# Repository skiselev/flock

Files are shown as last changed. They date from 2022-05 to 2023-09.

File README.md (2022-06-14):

# Flock
Floppy Disk Controller and Real Time Clock for RC2014 compatible systems

## Table of Content
* [Overview](#overview)
  * [Specifications](#specifications)
* [Assembly Instructions](#assembly-instructions)
* [Hardware Documentation](#hardware-documentation)
  * [Schematic and PCB Layout](#schematic-and-pcb-layout)
  * [Input/Output Ports](#inputoutput-ports)
  * [Connectors](#connectors)
  * [Bill of Materials](#bill-of-materials)
* [Release Notes](#release-notes)
  * [Changes](#changes)
  * [Known Issues](#known-issues)
* [Red Tape](#red-tape)
  * [Licensing](#licensing)
  * [Trademarks](#trademarks)

## Overview
Flock is an RC2014*-compatible floppy disk controller (FDC) and real time clock (RTC) module. It designed to work with RomWBW firmware, supporting CP/M, ZSDOS, and various applications under these OSes.

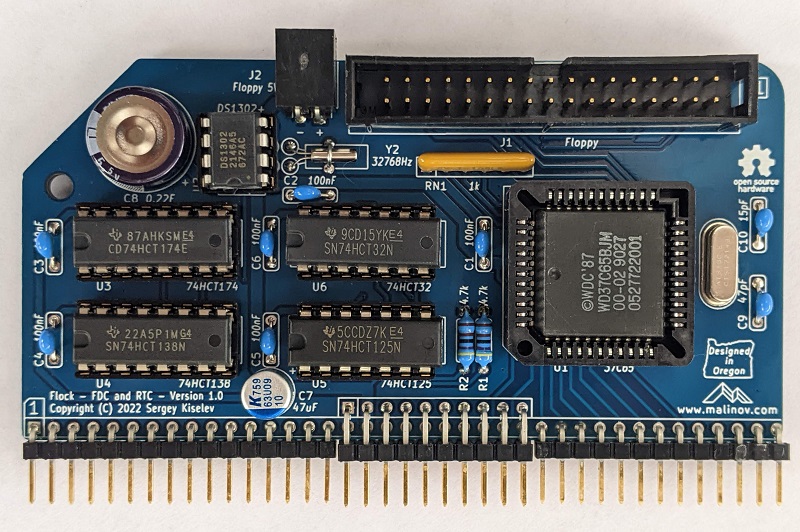
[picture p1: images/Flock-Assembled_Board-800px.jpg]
Flock Assembled Board


### Specifications
* Floppy Disk Controller: Western Digital* WD37C65 or compatible
  * NEC uPD765 compatible with an integrated data separator and floppy interface drivers and buffers
* Supported floppy disk formats:
  * 3.5", 720 KB
  * 3.5", 1.44 MB
  * 5.25", 360 KB (in 5.25", 360 KB drives only)
  * 5.25", 1.2 MB
* Supports two floppy drives, using IBM PC-like cable with twisted Disk Select / Motor Enable wires between two drives
* Real Time Clock: Maxim Integrated DS1302
* Bus: RC2014* compatible

## Assembly Instructions

Please refer to [Assembly Instructions](Assembly_Instructions.md) document

## Hardware Documentation

### Schematic and PCB Layout

[Schematic - Version 1.0](KiCad/Z80-FDC-Schematic-1.0.pdf)

[PCB Layout - Version 1.0](KiCad/Z80-FDC-Board-1.0.pdf)

### Input/Output Ports

Flock uses the following I/O ports:

#### 0x48 - FDC CCR/DIR

Write: Floppy disk controller control configuration register (CCR)
Read: Floppy disk controller digital input register (DIR)

#### 0x50 - FDC MSR

Read: Floppy disk controller master status register (MSR)

#### 0x51 - FDC Data Register

Read/Write: Data from/to floppy disk controller

#### 0x58 - FDC DOR / TC

Write: Floppy disk controller digital output register (DOR)
Read: Toggle floppy disk controller transfer complete (TC) line

#### 0xC0 - RTC

Read/Write: Access real time clock (RTC)

### Connectors

#### J1 - Floppy
Connect to floppy drive interface connector.

Pin   | Signal Name | Description | Pin   | Signal Name | Description
----- | ----------- | ------------| ----- | ----------- | -----------
J1-1  | GND         | Ground      | J1-2  | /DENSEL     | Density Select: 1 = Low density; 0 = High density
J1-3  | GND         | Ground      | J1-4  | N/C         | Not connected
J1-5  | GND         | Ground      | J1-6  | N/C         | Not connected
J1-7  | GND         | Ground      | J1-8  | /INDEX      | Index hole: 0 = At the index hole
J1-9  | GND         | Ground      | J1-10 | /MEA        | Motor Enable - Drive A
J1-11 | GND         | Ground      | J1-12 | /DSB        | Drive Select - Drive B
J1-13 | GND         | Ground      | J1-14 | /DSA        | Drive Select - Drive A
J1-15 | GND         | Ground      | J1-16 | /MEB        | Motor Enable - Drive B
J1-17 | GND         | Ground      | J1-18 | /DIR        | Direction Select
J1-19 | GND         | Ground      | J1-20 | /STEP       | Head Step
J1-21 | GND         | Ground      | J1-22 | /WDATA      | Write Data
J1-23 | GND         | Ground      | J1-24 | /WE         | Write Enable: 0 = Write Enabled
J1-25 | GND         | Ground      | J1-26 | /TRK0       | Track 00: 0 = At the track 0
J1-27 | GND         | Ground      | J1-28 | /WP         | Write Protect: 0 = Floppy disk is write protected
J1-29 | GND         | Ground      | J1-30 | /RDATA      | Read Data 
J1-31 | GND         | Ground      | J1-32 | /HDSEL      | Head Select / Side Select: 1 = Side 0; 0 = Side 1
J1-33 | GND         | Ground      | J1-34 | /DC         | Disk changed: 1 = Disk changed; 0 = Ready

#### J2 - Floppy 5V
Connect to floppy 5V power supply connector.

**Important: J2 is an unfused 5V power supply for a single 3.5" floppy disk drive. Avoid overloading and short-circuiting**

Pin | Signal Name | Description
--- | ----------- | -----------
1   | 5V          | Positive terminal - +5V
2   | GND         | Negative terminal - ground

#### J3, J4 - RC2014* Bus
Pin   | Signal Name | Description         | Pin  | Signal Name | Description
----- | ----------- | --------------------------------------- | ----- | ----------- | -----------
J3-1  | A15         | Address A15; Output                     |       |             |
J3-2  | A14         | Address A14; Output                     |       |             |
J3-3  | A13         | Address A13; Output                     |       |             |
J3-4  | A12         | Address A12; Output                     |       |             |
J3-5  | A11         | Address A11; Output                     |       |             |
J3-6  | A10         | Address A10; Output                     |       |             |
J3-7  | A9          | Address A9; Output                      |       |             |
J3-8  | A8          | Address A8; Output                      |       |             |
J3-9  | A7          | Address A7; Output                      |       |             |
J3-10 | A6          | Address A6; Output                      |       |             |
J3-11 | A5          | Address A5; Output                      |       |             |
J3-12 | A4          | Address A4; Output                      |       |             |
J3-13 | A3          | Address A3; Output                      |       |             |
J3-14 | A2          | Address A2; Output                      |       |             |
J3-15 | A1          | Address A1; Output                      |       |             |
J3-16 | A0          | Address A0; Output                      |       |             |
J3-17 | GND         | Ground                                  | J4-1  | GND         | Ground
J3-18 | VCC         | Power Supply - +5V                      | J4-2  | VCC         | Power Supply - +5V
J3-19 | /M1         | Machine Cycle One; Output               | J4-3  | /RFSH       | DRAM refresh; Output
J3-20 | /RESET      | Reset; Output                           | J4-4  | N/C         | Not connected
J3-21 | CLK1        | CPU Clock; Output                       | J4-5  | CLK2        | UART Clock (programmable); Output
J3-22 | /INT        | Interrupt; Input                        | J4-6  | /BUSACK     | DMA Bus Acknowledge; Output
J3-23 | /MREQ       | Memory Request; Output                  | J4-7  | /HALT       | Halt; Output
J3-24 | /WR         | Write Request; Output                   | J4-8  | /BUSREQ     | DMA Bus Request; Input
J3-25 | /RD         | Read Request; Output                    | J4-9  | /WAIT       | Wait; Input
J3-26 | /IORQ       | Input/Output Request; Output            | J4-10 | /NMI        | Non-maskable Interrupt; Input
J3-27 | D0          | Data D0; Input/Output                   |       |             |
J3-28 | D1          | Data D1; Input/Output                   |       |             |
J3-29 | D2          | Data D2; Input/Output                   |       |             |
J3-30 | D3          | Data D3; Input/Output                   |       |             |
J3-31 | D4          | Data D4; Input/Output                   |       |             |
J3-32 | D5          | Data D5; Input/Output                   |       |             |
J3-33 | D6          | Data D6; Input/Output                   |       |             |
J3-34 | D7          | Data D7; Input/Output                   |       |             |
J3-35 | TXDA        | Channel A, Transmit Data; Not Connected |       |             | 
J3-36 | RXDA        | Channel A, Receive Data; Not Connected  |       |             | 
J3-37 | USR1        | User Pin 1; Not connected               |       |             |
J3-38 | USR2        | User Pin 2; Not connected               |       |             |
J3-39 | USR3        | User Pin 3; Not connected               |       |             |

### Bill of Materials

#### Version 1.0

[Flock project on Mouser.com](https://www.mouser.com/ProjectManager/ProjectDetail.aspx?AccessID=5b60f70b94) - View and order all components except of the FDC and the PCB.

[Flock project on OSH Park](https://oshpark.com/shared_projects/BpUjKD43) - View and order the PCB.

Flock project on Tindie: [Complete kit](https://www.tindie.com/products/weird/flock-rc2014-compatible-module-kit/); [Flock PCB and FDC](https://www.tindie.com/products/weird/flock-rc2014-compatible-module-pcb-and-fdc/).

Component type     | Reference | Description                                 | Quantity | Possible sources and notes 
------------------ | --------- | ------------------------------------------- | -------- | --------------------------
PCB                |           | Flock PCB - Version 1.0                     | 1        | Buy from my Tindie store: [Complete kit](https://www.tindie.com/products/weird/flock-rc2014-compatible-module-kit/); [Flock PCB and FDC](https://www.tindie.com/products/weird/flock-rc2014-compatible-module-pcb-and-fdc/), or order from a PCB manufacturer of your choice using provided Gerber or KiCad files
Integrated Circuit | U1        | WD37C65BJM - FDC, CMOS, 44 pin PLCC         | 1        | eBay. Alternative: ST AIC37C65CL
Integrated Circuit | U2        | DS1302+ - RTC, 8 pin DIP                    | 1        | Mouser [700-DS1302](https://www.mouser.com/ProductDetail/700-DS1302)
Integrated Circuit | U3        | 74HCT174 - Hex D-type flip-flop with reset, 16 pin DIP | 1 | Mouser [595-CD74HCT174E](https://www.mouser.com/ProductDetail/595-CD74HCT174E)
Integrated Circuit | U4        | 74HCT138 - 3-Line to 8-Line decoders/demultiplexers, 16 pin DIP| 1 | Mouser [595-SN74HCT138NE4](https://www.mouser.com/ProductDetail/595-SN74HCT138NE4)
Integrated Circuit | U5        | 74HCT125 - Quadruple bus buffer gates with 3-state outputs, 14 pin DIP | 1 | Mouser [595-SN74HCT125NE4](https://www.mouser.com/ProductDetail/595-SN74HCT125NE4)
Integrated Circuit | U6        | 74HCT32 - Quadruple 2-input positive-OR gates, 14 pin DIP | 1 | Mouser [595-SN74HCT32NE4](https://www.mouser.com/ProductDetail/595-SN74HCT32NE4)
Quartz Crystal     | Y1        | 16 MHz, series                              | 1        | Mouser [774-ATS160-E](https://www.mouser.com/ProductDetail/774-ATS160-E)
Quartz Crystal     | Y2        | 32768 Hz, 6 pF                              | 1        | Mouser [815-AB26T32768KHZ6B](https://www.mouser.com/ProductDetail/815-AB26T32768KHZ6B)
Connector          | J1        | 2x17 pin header, shrouded, 2.54 mm pitch    | 1        | Mouser [517-30334-6002](https://www.mouser.com/ProductDetail/517-30334-6002); Alternative: Mouser [855-M20-9741746](https://www.mouser.com/ProductDetail/855-M20-9741746) (not shrouded, right angle)
Connector          | J2        | 2 pin header with friction lock, right angle | 1       | Mouser [571-2-644488-2](https://www.mouser.com/ProductDetail/571-2-644488-2)
Pin Header         | J3, J4    | 2x40 pin header, 2.54 mm pitch, right angle | 1        | Mouser [517-5121TG](https://www.mouser.com/ProductDetail/517-5121TG), or two [649-77315-118-16LF](https://www.mouser.com/ProductDetail/649-77315-118-16LF) and one [649-77317-104-20LF](https://www.mouser.com/ProductDetail/649-77317-104-20LF)
Capacitor          | C1 - C6   | 0.1 uF, 50V, MLCC, 5 mm pitch               | 6        | Mouser [810-FG28X7R1H104KNT6](https://www.mouser.com/ProductDetail/810-FG28X7R1H104KNT6)
Capacitor          | C7        | 10 uF, 63V, Organic Polymer, 6.3 mm diameter, 2.5 mm pitch | 1 | Mouser [80-A759EA106M1JAAE60](https://www.mouser.com/ProductDetail/80-A759EA106M1JAAE60)
Capacitor          | C8        | 0.22 F, 5.5V, Supercapacitor, 13.5 mm diameter, 5 mm pitch | 1 | Mouser [555-DBN-5R5D334T](https://www.mouser.com/ProductDetail/555-DBN-5R5D334T)
Capacitor          | C9        | 47 pF, 50V, MLCC, 5 mm pitch                | 6        | Mouser [810-FG28C0G2A470JNT0](https://www.mouser.com/ProductDetail/810-FG28C0G2A470JNT0)
Capacitor          | C10       | 15 pF, 50V, MLCC, 5 mm pitch                | 6        | Mouser [810-FG28C0G2A150JNT0](https://www.mouser.com/ProductDetail/810-FG28C0G2A150JNT0)
Resistor Array     | RN1       | 1 kohm, bussed, 6 pin SIP                   | 1        | Mouser [652-4606X-1LF-1K](https://www.mouser.com/ProductDetail/652-4606X-1LF-1K)
Resistor           | R1,  R2   | 4.7 kohm, 0.25 W, 1% tolerance, axial       | 2        | Mouser [603-MFR-25FRF52-4K7](https://www.mouser.com/ProductDetail/603-MFR-25FRF52-4K7)
IC Socket          | U1        | 44 pin PLCC, through hole                   | 1        | Mouser [517-8444-11B1-RK-TP](https://www.mouser.com/ProductDetail/517-8444-11B1-RK-TP)
IC Socket          | U2        | 8 pin DIP                                   | 1        | Mouser [649-DILB8P223TLF](https://www.mouser.com/ProductDetail/649-DILB8P223TLF)
IC Socket          | U3, U4    | 16 pin DIP                                  | 1        | Mouser [649-DILB16P-223TLF](https://www.mouser.com/ProductDetail/649-DILB16P-223TLF)
IC Socket          | U5, U6    | 14 pin DIP                                  | 1        | Mouser [649-DILB14P-223TLF](https://www.mouser.com/ProductDetail/649-DILB14P-223TLF)
Connector          | J2        | 2 pin connector                             | 1        | Mouser [571-3-643813-2](https://www.mouser.com/ProductDetail/571-3-643813-2)
Connector          | J2        | Floppy disk power connector housing         | 1        | Mouser [571-1718224](https://www.mouser.com/ProductDetail/571-1718224)
Connector          | J2        | Floppy disk power connector contacts        | 2        | Mouser [571-170262-2-LP](https://www.mouser.com/ProductDetail/571-170262-2-LP), [571-1702622-CT](https://www.mouser.com/ProductDetail/571-1702622-CT) (strip of 100 contacts)

## Release Notes

### Changes

* Version 1.0
  * Initial version

### Known Issues

* Version 1.0
  * No known issues

### Wishlist
* None so far

## Red Tape

### Licensing

Flock is an open source hardware project certified by [Open Source Hardware Association](https://www.oshwa.org/), certification UID is [US002115](https://certification.oshwa.org/us002115.html). The hardware design itself, including schematic and PCB layout design files are licensed under the strongly-reciprocal variant of [CERN Open Hardware Licence version 2](license-cern_ohl_s_v2.txt). The CPLD VHDL code is licensed under [GNU General Public License v3](license-gpl-3.0.txt). Documentation, including this file, is licensed under the [Creative Commons Attribution-ShareAlike 4.0 International License](license-cc-by-sa-4.0.txt).

CERN-OHL-2.0-S, GPL-3.0, CC-BY-SA-4.0

### Trademarks

* "RC2014" is a registered trademark of RFC2795 Ltd.
* Other names and brands may be claimed as the property of others.

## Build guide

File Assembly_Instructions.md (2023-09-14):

# Flock - Assembly Instructions

## Prerequisites

### Tools, Equipment, and Supplies

* Soldering iron with a fine tip. Temperature controlled soldering station is recommended
* Needle nose pliers for forming components' leads
* Small side cutters for cutting components' leads
* Multimeter with frequency measurement, an oscilloscope, or a logic analyzer can be beneficial for troubleshooting
* Desk lamp, magnifying glass
* Solder suitable for soldering electronics. For example: rosin core Sn63/Pb37, Sn60/Pb40, or a lead-free solder such as Sn96.5/Ag3.0/Cu0.5 (sometimes referred to as SAC305)
* Solder wick for removing excess of solder
* 99% Isopropyl Alcohol for removing the excess of flux after soldering
* Lint free wipes, used toothbrush, cotton swabs for cleaning the PCB before and after soldering

### Parts

The table below shows the images of the components included in the kit. The up to date list of parts provided in the [Bill of Materials](README.md#bill-of-materials) section of the [README.md](README.md) file. It also provides the recommended sources for the parts.

Image                                                                                           | Reference | Description                                            | Quantity
----------------------------------------------------------------------------------------------- | --------- | ------------------------------------------------------ | --------
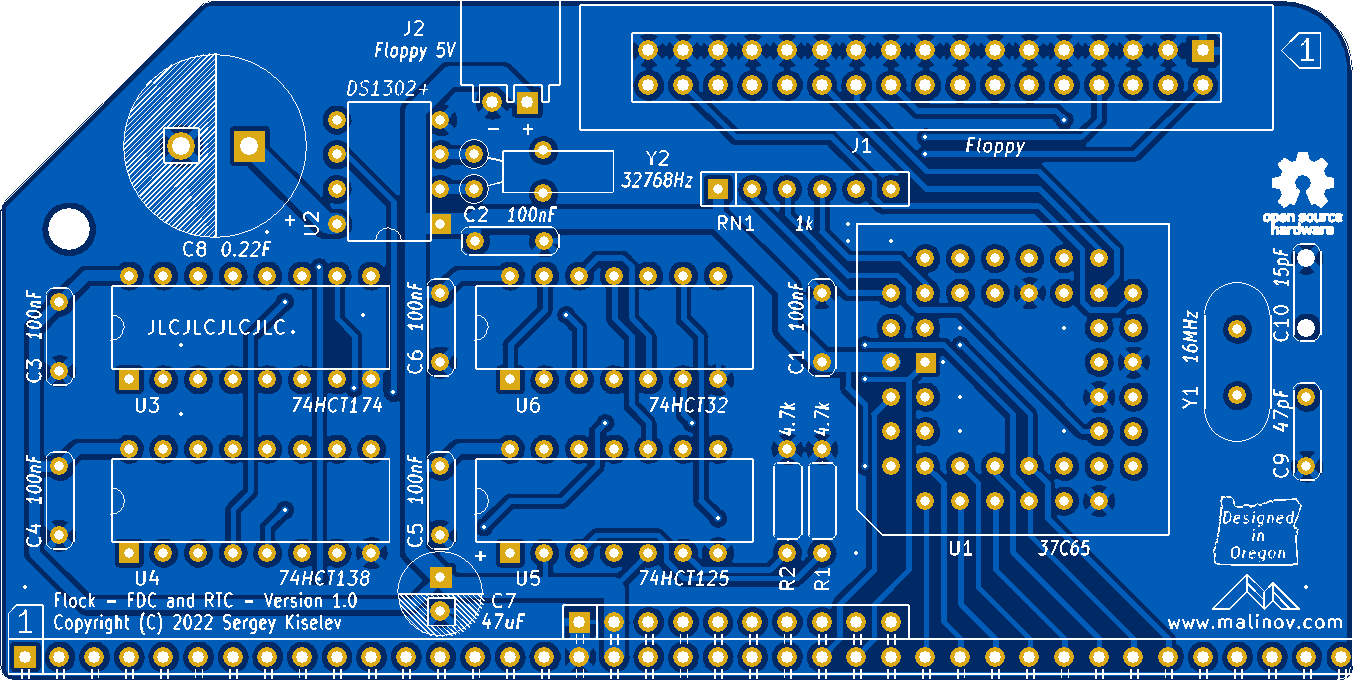
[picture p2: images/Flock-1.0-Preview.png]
PCB - Z80-512K v1.2
                 | PCB       | Flock PCB - Version 1.0                                | 1
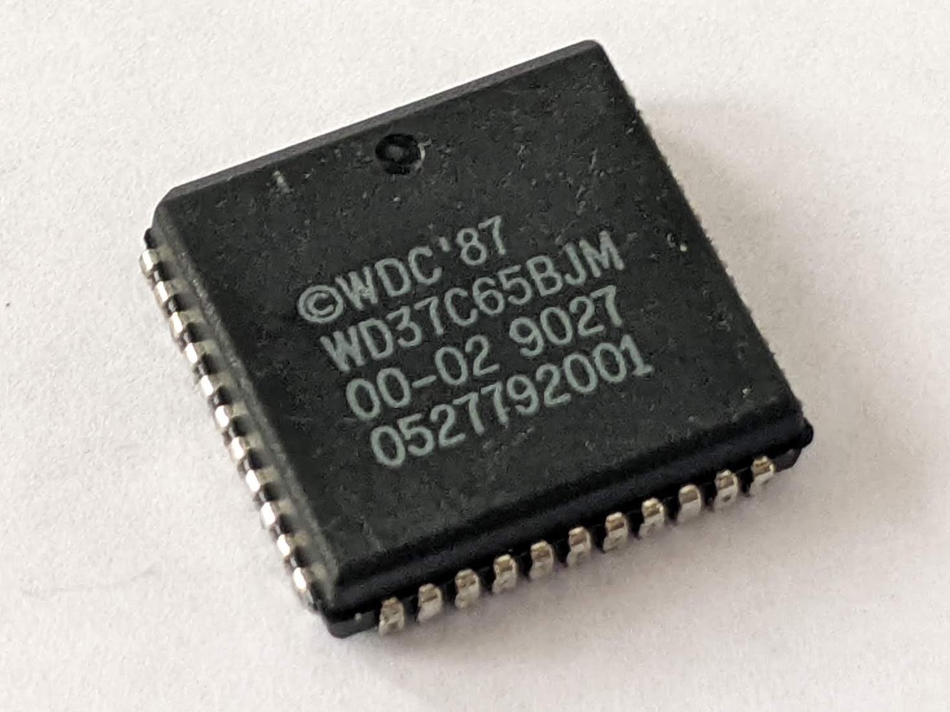
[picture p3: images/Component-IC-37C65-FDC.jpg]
FDC - 37C65
                    | U1        | WD37C65BJM - FDC, CMOS, 44 pin PLCC                    | 1
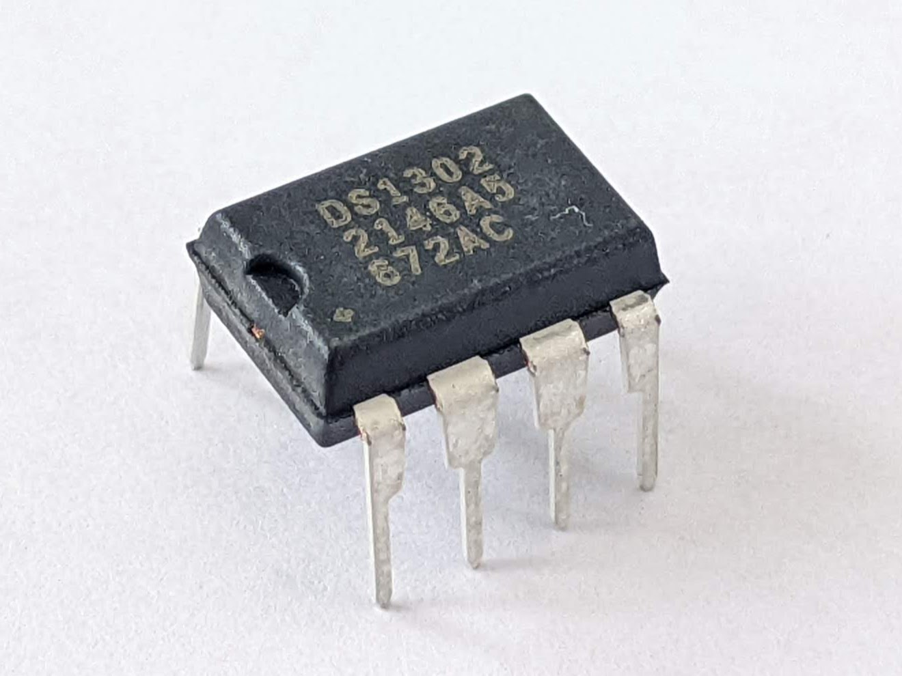
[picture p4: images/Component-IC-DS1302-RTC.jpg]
RTC - DS1302+
                 | U2        | DS1302+ - RTC, 8 pin DIP                               | 1
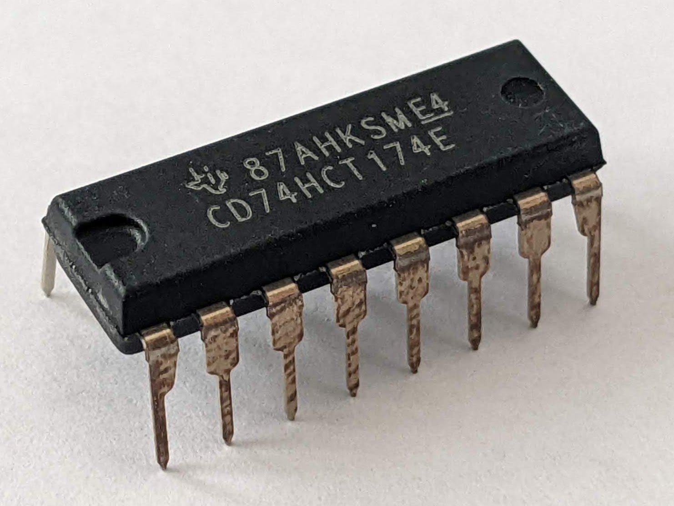
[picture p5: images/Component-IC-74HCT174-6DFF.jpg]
Hex D Flip-Flop - 74HCT174
 | U3        | 74HCT174 - Hex D-type flip-flop with reset, 16 pin DIP | 1
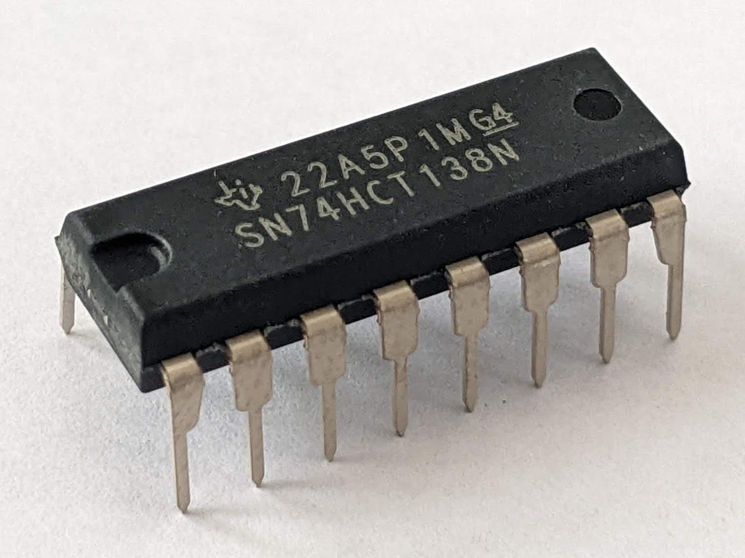
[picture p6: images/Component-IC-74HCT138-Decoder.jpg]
3 to 8 Decoder - 74HCT138
 | U4      | 74HCT138 - 3-Line to 8-Line decoders/demultiplexers, 16 pin DIP        | 1
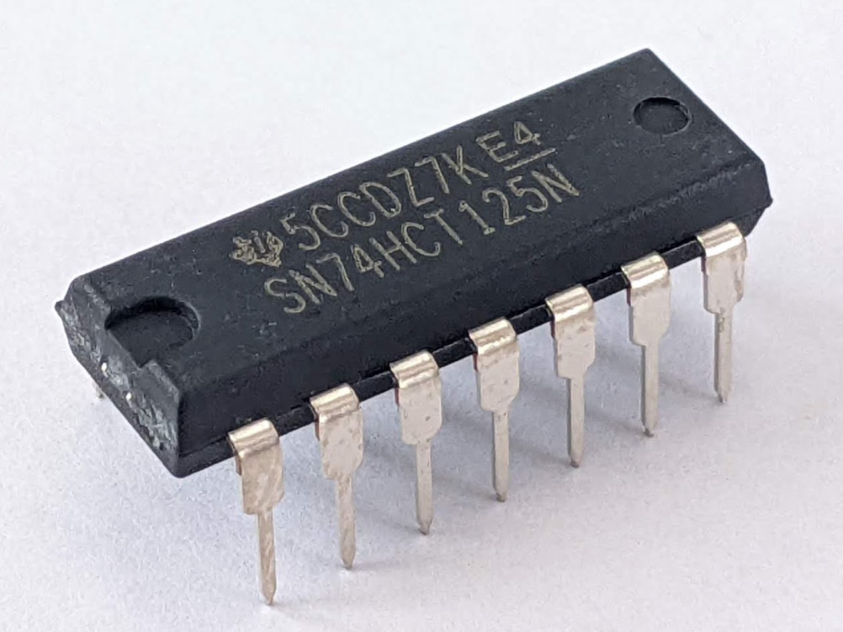
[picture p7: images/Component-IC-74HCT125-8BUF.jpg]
3-State Buffer - 74HCT125
  | U5        | 74HCT125 - Quadruple bus buffer gates with 3-state outputs, 14 pin DIP | 1 
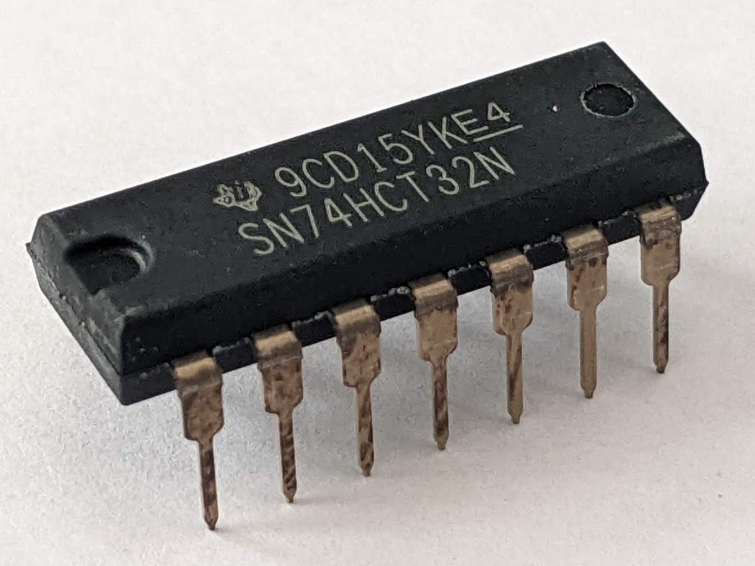
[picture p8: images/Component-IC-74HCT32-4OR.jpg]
4 OR Gates - 74HCT32
         | U6        | 74HCT32 - Quadruple 2-input positive-OR gates, 14 pin DIP              | 1
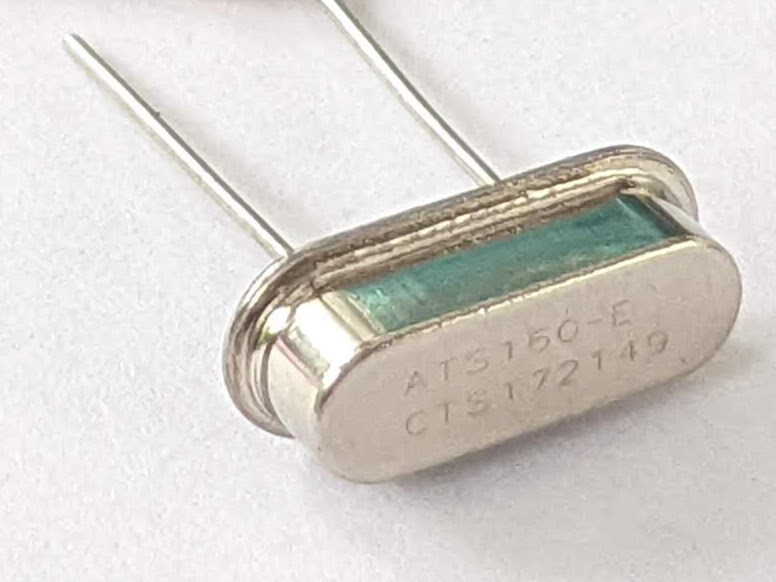
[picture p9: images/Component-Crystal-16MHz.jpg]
16 MHz Quartz Crystal
         | Y1        | Quarts crystal, 16 MHz, series                         | 1
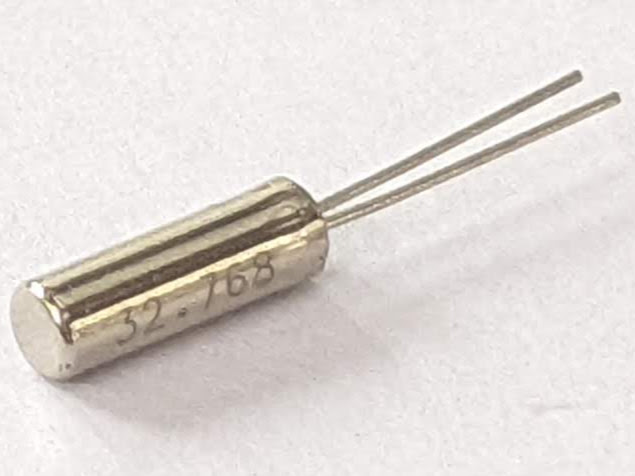
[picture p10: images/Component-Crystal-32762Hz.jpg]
32762 Hz Quartz Crystal
     | Y2        | Quarts crystal, 32768 Hz, 6 pF                         | 1
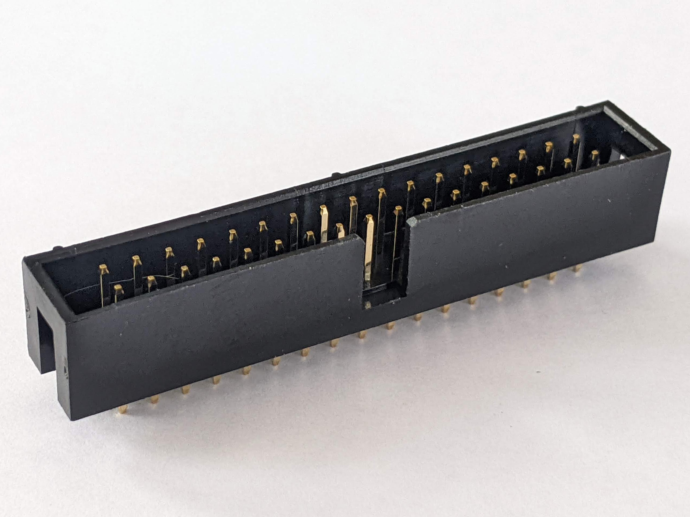
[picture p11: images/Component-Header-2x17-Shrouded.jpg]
2x17 Shrouded Pin Header
 | J1      | Pin header, shrouded, 2x17 pins, 2.54 mm pitch         | 1
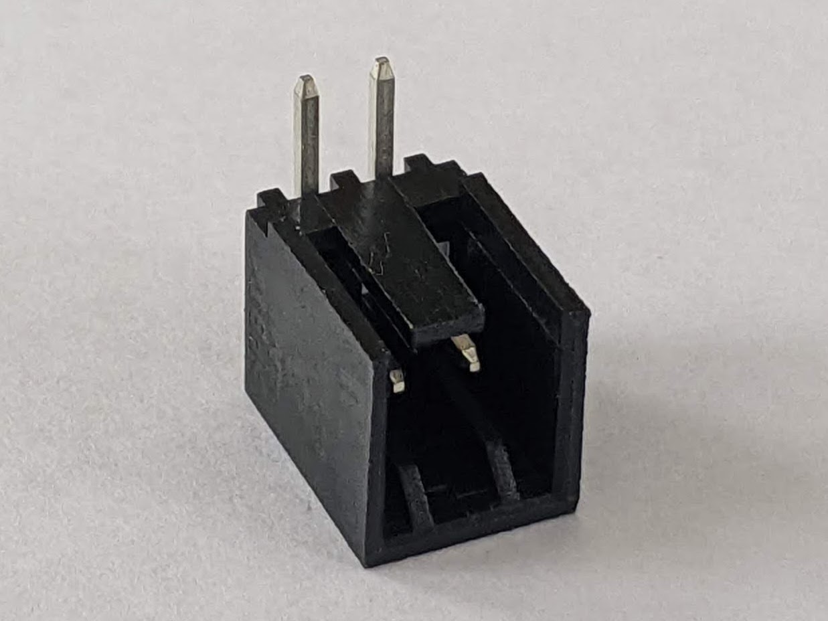
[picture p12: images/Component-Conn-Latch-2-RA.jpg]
Friction Lock Connector
     | J2        | Pin header with friction lock, 2 pins, right angle     | 1 (optional)
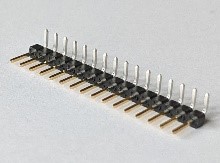
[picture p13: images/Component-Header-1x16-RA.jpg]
Pin Header 1x16 Right Angle
  | J3        | Pin header, 1x16 pins, 2.54 mm pitch, right angle      | 2
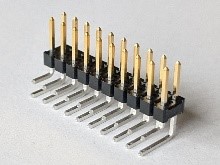
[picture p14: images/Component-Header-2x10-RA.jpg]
Pin Header 2x10 Right Angle
  | J3, J4    | Pin header, 2x10 pins, 2.54 mm pitch, right angle      | 1
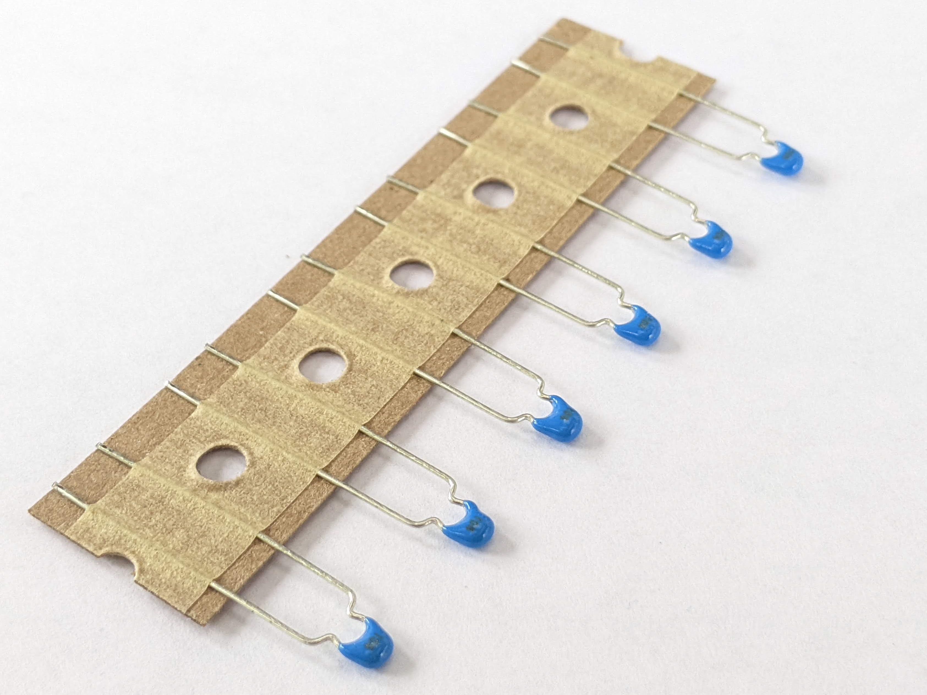
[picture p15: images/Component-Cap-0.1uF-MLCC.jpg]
Ceramic Capacitors - 0.1uF
   | C1 - C6   | Capacitor, MLCC, 0.1 uF, 50V, 5 mm pitch               | 6
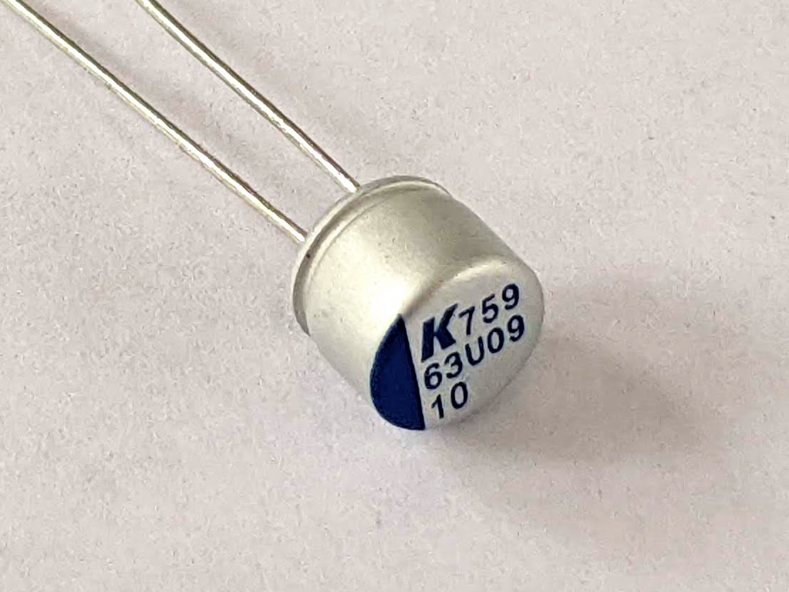
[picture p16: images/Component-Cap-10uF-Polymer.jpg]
Organic Polymer Capacitor - 10uF
 | C7  | Capacitor, Organic Polymer, 10 uF, 63V, 6.3 mm diameter, 2.5 mm pitch | 1
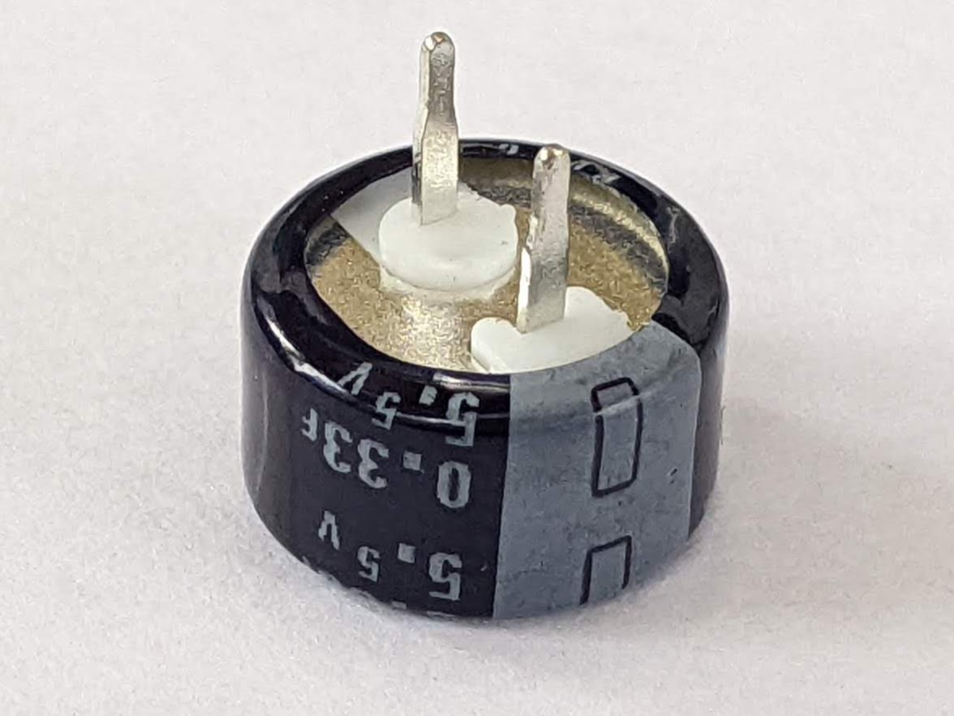
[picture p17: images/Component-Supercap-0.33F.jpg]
Supercapacitor - 0.33F
       | C7        | Supercapacitor, 0.22 F, 5.5V, 13.5 mm diameter, 5 mm pitch            | 1
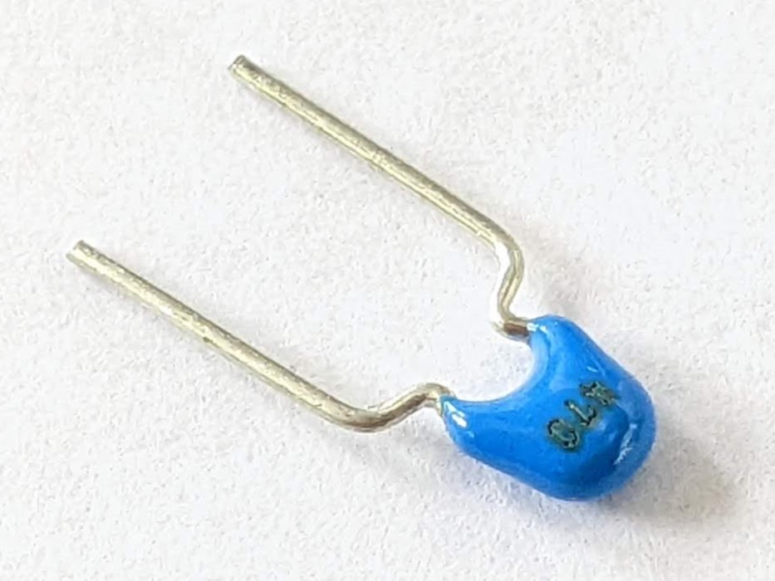
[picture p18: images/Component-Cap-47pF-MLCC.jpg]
Ceramic Capacitor - 47pF
      | C9        | Capacitor, MLCC, 47 pF, 50V, 5 mm pitch                | 1
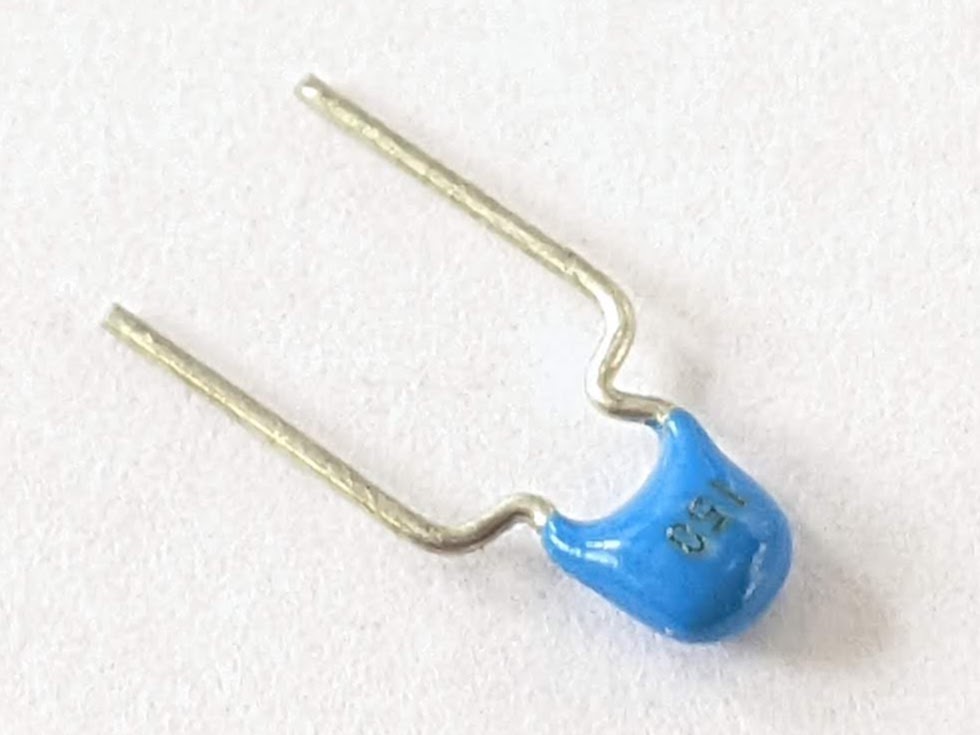
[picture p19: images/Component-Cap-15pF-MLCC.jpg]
Ceramic Capacitor - 15pF
      | C10       | Capacitor, MLCC, 15 pF, 50V, 5 mm pitch                | 1
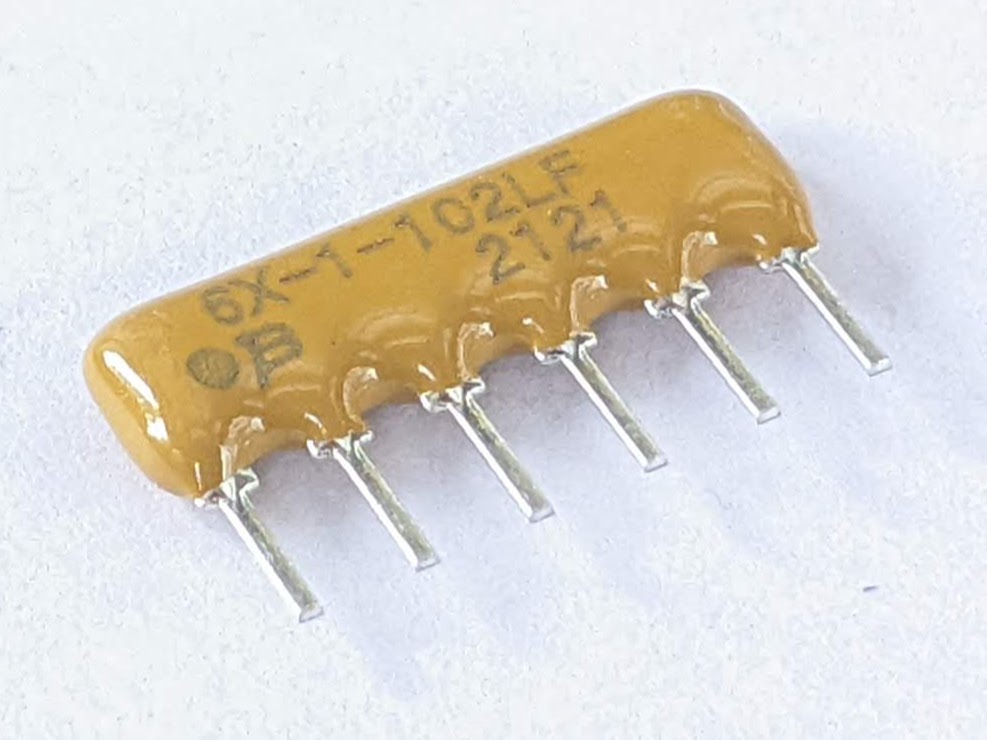
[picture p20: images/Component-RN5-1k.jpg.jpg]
Resistor Network - 5x1k
          | RN1       | Resistor Network, 1 kohm, bussed, 6 pin SIP            | 1
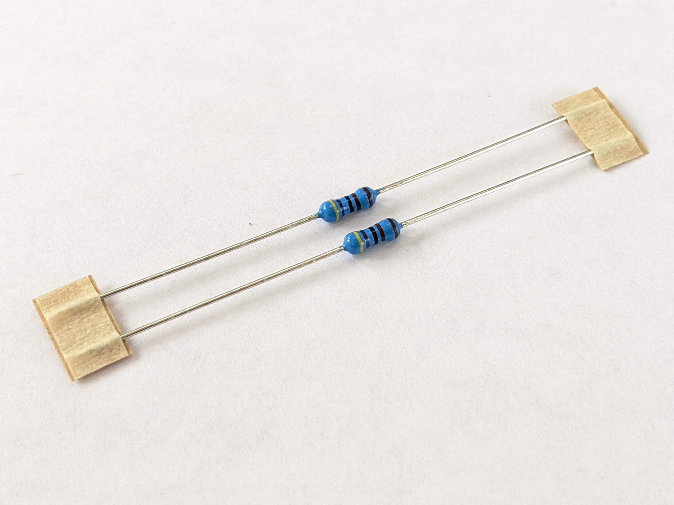
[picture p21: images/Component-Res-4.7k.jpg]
Resistors - 4.7k
                   | R1, R2    | Resistor, 4.7 kohm, 0.25 W, 1% tolerance, axial        | 2
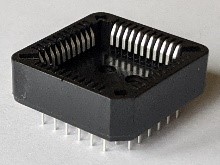
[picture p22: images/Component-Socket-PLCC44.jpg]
IC Socket - PLCC44
            | U1        | Integrated circuit socket, 44 pin PLCC, through hole   | 1
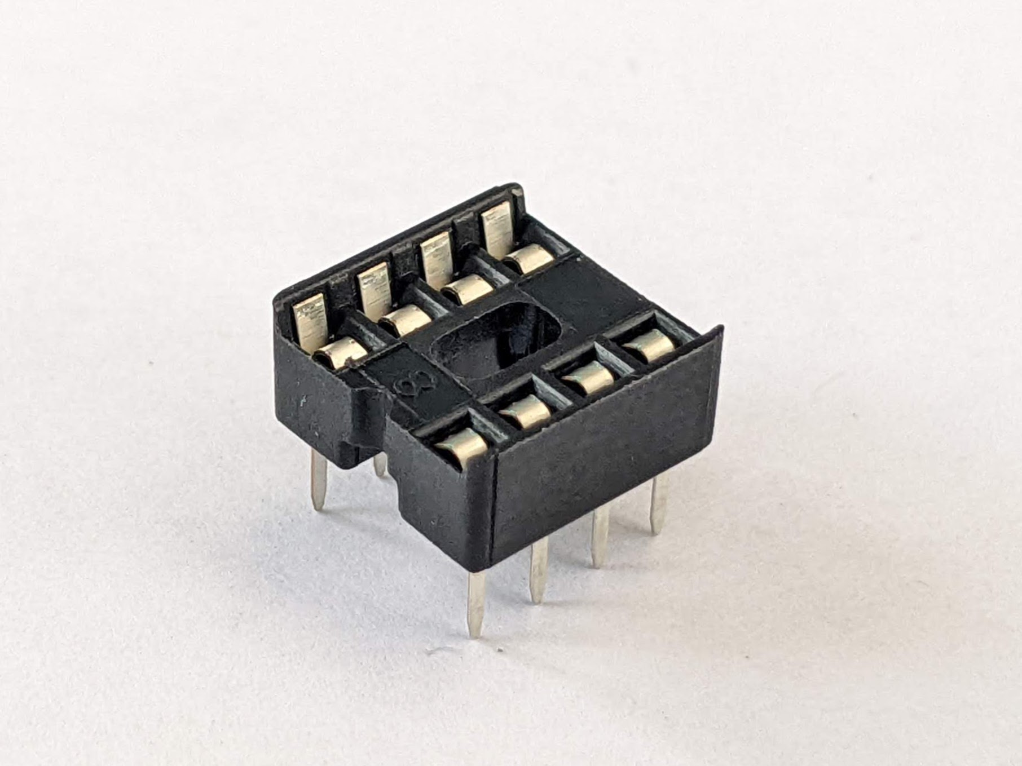
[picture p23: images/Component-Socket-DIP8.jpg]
IC Socket - DIP8
                | U2        | Integrated circuit socket, 8 pin DIP                   | 1 (optional)
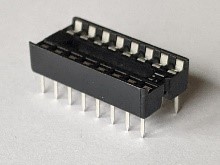
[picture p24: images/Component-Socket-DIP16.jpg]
IC Socket - DIP16
              | U3, U4    | Integrated circuit socket, 16 pin DIP                  | 2 (optional)
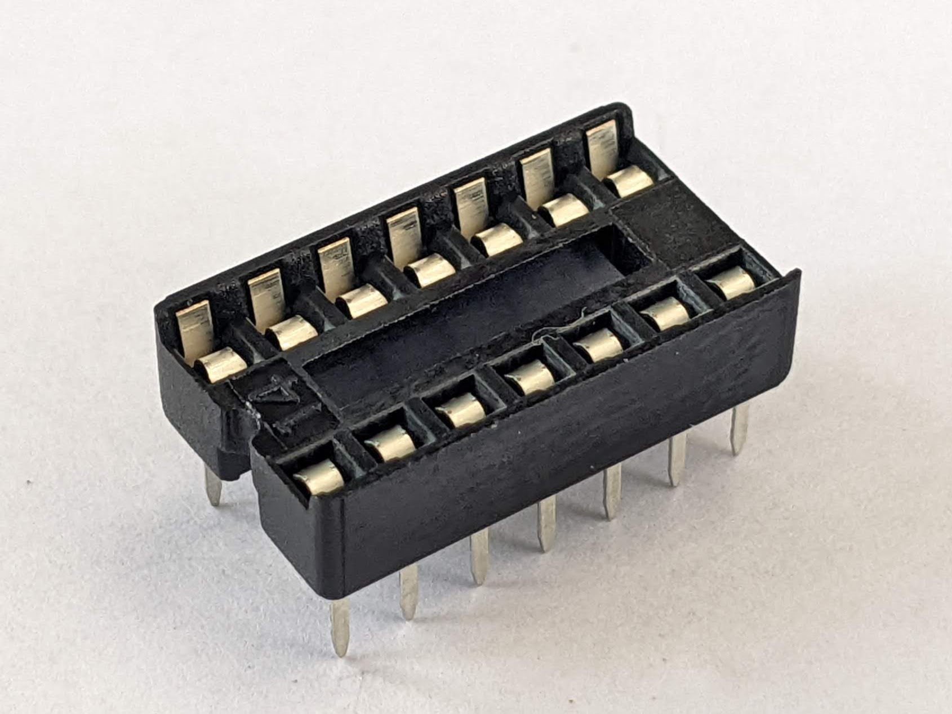
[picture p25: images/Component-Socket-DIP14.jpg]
IC Socket - DIP16
              | U5, U6    | Integrated circuit socket, 14 pin DIP                  | 2 (optional)
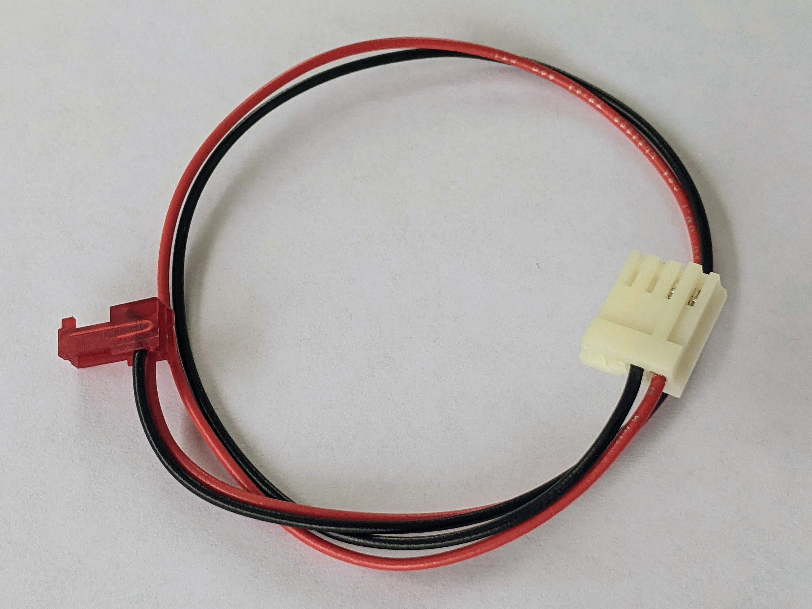
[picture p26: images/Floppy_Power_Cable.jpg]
Floppy power cable
                 |           | Floppy disk power cable                                | 1 (optional)

## Assembly Steps

### 1. Gather supplies and parts

* Check that you have all the equipment and parts listed in the [Prerequisites](#prerequisites) section above
* Organize your workspace. If available, use ESD-safe surface and ESD strap when working on this project

### 2. Solder the components

Solder the components to the PCB going from lower profile components to higher profile components, from smaller components to larger. Here is the recommended order:

* Start by soldering the R1 and R2 resistors. The resistors are not polarized and can be oriented either way. Trim the leads using cutters
* Next solder the Y1 and Y2 quartz crystals. Make a U-shaped loop using a resistor lead cut in the previous step, and secure Y2 to the PCB with that loop
* Solder RN1 resistor array. Make sure that the resistor array is oriented correctly. The first pin of the resistor array is marked with a printed dot, and the first pad on the board has a square shape
* Solder the C1 - C6, C9, and C10 capacitors. Note that these are non-polarized ceramic capacitors, so they can be oriented either way. Trim the leads using cutters
  * C1 – C6 have a “104” marking
  * C9 has “470” marking
  * C10 has “150” marking
* Solder DIP sockets for the U2 – U6 ICs. Double check the orientation of the sockets. The notch on the socket should match the notch on the PCB’s silkscreen.
Solder two opposite pins first, making sure that the socket sits flat on the PCB. Check the orientation and the alignment, fix as needed,
then solder the rest of the pins. Note that soldering the socket for U2 is optional. The real time clock would be more accurate without it,
as the socket introduces extra capacitance. You may choose to solder the DS1302 directly to the PCB at this step
*	Solder the PLCC socket for the U1 IC. Make sure that the cut side of the socket aligns with the drawing on the silkscreen
* Solder the J3 and J4 RC2014* bus connectors. Shorten one of 1x16 pin headers to 1x13 by carefully cutting or breaking away 3 pins.
Solder the 2x10 pin header first, making sure that the pins are parallel to the PCB. Next solder 1x16 and 1x13 pin headers,
making sure that they align with the first (bottom) row of the 2x10 pin header
*	Solder the J2 floppy power connector. This connector is optional. You might choose to power the floppy drive(s) directly from the power supply instead
* Solder the J1 floppy interface connector. Pay attention to the pin 1 orientation – it should be at the top right corner of the PCB,
and the polarization key notch in the connector should be located by the top edge of the PCB. Note: the kit includes a straight connector.
You might choose to replace it with a right angle pin header (not supplied) to simplify the floppy interface cable routing
and reduce intereference with the next module in the backplane. Note that you may need to remove/extract pin 3 from this connector to accommodate some floppy cables which have this pin position blocked.
*	Solder the C7 and C8 capacitors. Pay attention to the __polarity__ – the negative side is painted white on the PCB and marked with blue (C7)
or gray with minus signs (C8) markings. Note that C7 is marked as 47uF on the PCB, and C8 is marked as 0.22F.
Install the supplied 10uF and 0.33F capacitors respectively instead

### 3. Check your soldering work

* Make sure all pins of all components are soldered properly
* If desired, clean the flux using isopropyl alcohol, cotton swabs. You might want to scrub the board lightly with a used toothbrush to remove the flux
* Check soldering work again after cleaning the board

### 4. Insert the integrated circuits to the sockets
* Prior to inserting DIP integrated circuits to the sockets board, bend their leads slightly, so they point 90 degrees downward. Put the IC on the side on a hard flat antistatic surface and gently push it down to bend the leads. Repeat on the other side of the IC
* Double check that you're placing the integrated circuit in the right socket, check the IC orientation. The index notch on the IC should match the notch on the socket and the drawing on the PCB's silkscreen
* To insert the 37C65 FDC integrated circuit in PLCC44 package, place it on the top of the socket, double check the orientation of the integrated circuit, and firmly push it down. It should click into the socket

Assembled board

## Module Installation Instructions

* Make sure that your RC2014*-compatible system has I/O port ranges 0x48-0x5F and 0xC0-0xC8 available for the Flock module use. If needed re-configure existing modules, and move them to other I/O addresses
* Plug the module into your system
* Connect the floppy drive(s) to the board. Standard IBM PC ribbon floppy cable with twisted wires 10-16 should be used (not supplied). The first floppy drive is the one at the end of the cable, the second is on the middle of the cable
* Connect the floppy drive(s) to power supply. A single 3.5” 1.44 MB drive can be powered directly from the Flock board, using supplied power cable. Make sure to use powerful enough power supply. The floppy drive consumes about 1A
* Rebuild RomWBW with floppy support or use the pre-built image provided in the project’s GitHub repo. Here are the brief steps to rebuild the image. See [https://github.com/wwarthen/RomWBW/blob/master/Source/ReadMe.txt](https://github.com/wwarthen/RomWBW/blob/master/Source/ReadMe.txt) for complete instructons:
    a. Download the RomWBW source or clone its Git repository: [https://github.com/wwarthen/RomWBW/releases](https://github.com/wwarthen/RomWBW/releases)
  1. Open the _Source/HBIOS/Config/RCZ80_std.asm file_ in a text editor, and set _FDENABLE_ value to _TRUE_
  2. From the _Source_ folder, run the **BuildShared** command. This will build software that is shared by all RomWBW images
  3. From the _Source_ folder, run the **BuildRom** command. Select “RCZ80” platform and “std” configuration
  4. The resulting ROM image will be located in the Binary folder and will be named _RCZ80_std.rom_. Program the image to your systems’ flash ROM using either an EPROM programmer or FLASH4 command
* Power on your system. Verify that RomWBW shows DSRTC: device, reads the time from the RTC, shows FD: device, and displays floppy disk drives as shown in the screenshot below:

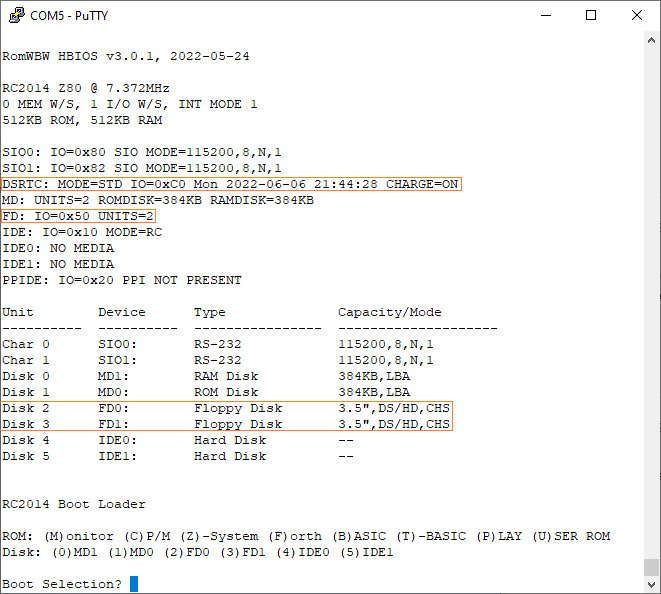
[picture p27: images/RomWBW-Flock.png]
RomWBW Boot Screen with Flock


## Module Usage Instructions – Floppy Disk Controller
The FDU utility included in RomWBW and can be used to test the floppy disk controller and to format floppy disks
*	Boot your system to CP/M or ZSDOS and run the **FDU** command. Type **H** to select “(H) RC2014 WDC (SMB)”
*	Use the **S** command to set the floppy disk configuration. Select the correct media type (e.g., enter “01” for 1.44 MB disks), leave the default settings for mode and trace
*	Use the **F** command to format the floppy disk. Note that all information on the disk will be destroyed
*	Use the **R** and **W** commands to test reading from and writing to the floppy disk
Once formatted, the floppy disk can be accessed from CP/M and ZSDOS. RomWBW normally assigns letters _C:_ and _D:_ to the first and the second floppy drives respectively

## Module Usage Instructions – FAT12 Floppy formatting
The FAT utility included with RomWBW will format floppies to FAT12, rendering them writable on modern computers.
*	Boot your system to an OS which supports the FAT utility (I.E. ZP/M). 
*	Observe the disk unit number when booting your system for FD0 (I.E. Disk 2)
*	Run **FAT FORMAT 2:** and be absolutely sure your disk unit number is correct.  
*	Wait for the format to complete.
Once formatted, the disk can be used with a modern computer, such as with a USB to 1.44 Floppy drive. The floppy disk can be accessed only using the FAT utility on RomWBW; Formatting a disk this way is primarily to use it for a bridge to a modern machine. The FAT utility is used to copy files between your CP/M etc. system storage, and the FAT formatted floppy disk.

## Module Usage Instructions – Real Time Clock
The RTC utility included in RomWBW is used to set and test the real time clock
*	Boot your system to CP/M or ZSDOS and run the **RTC** command
*	Use the **I** command to enter the current date and time. Use two digit values for each entry
*	Use the **S** command to set the RTC to the time entered in the previous step with I command
*	Use the **T** command to print the current time. Check that the time is set correctly and RTC properly updates the time
*	Use the **C** command to enable trickle charge, so that DS1302 will be charing the on-board supercapacitor

__Congratulations! Enjoy your Flock Module!__

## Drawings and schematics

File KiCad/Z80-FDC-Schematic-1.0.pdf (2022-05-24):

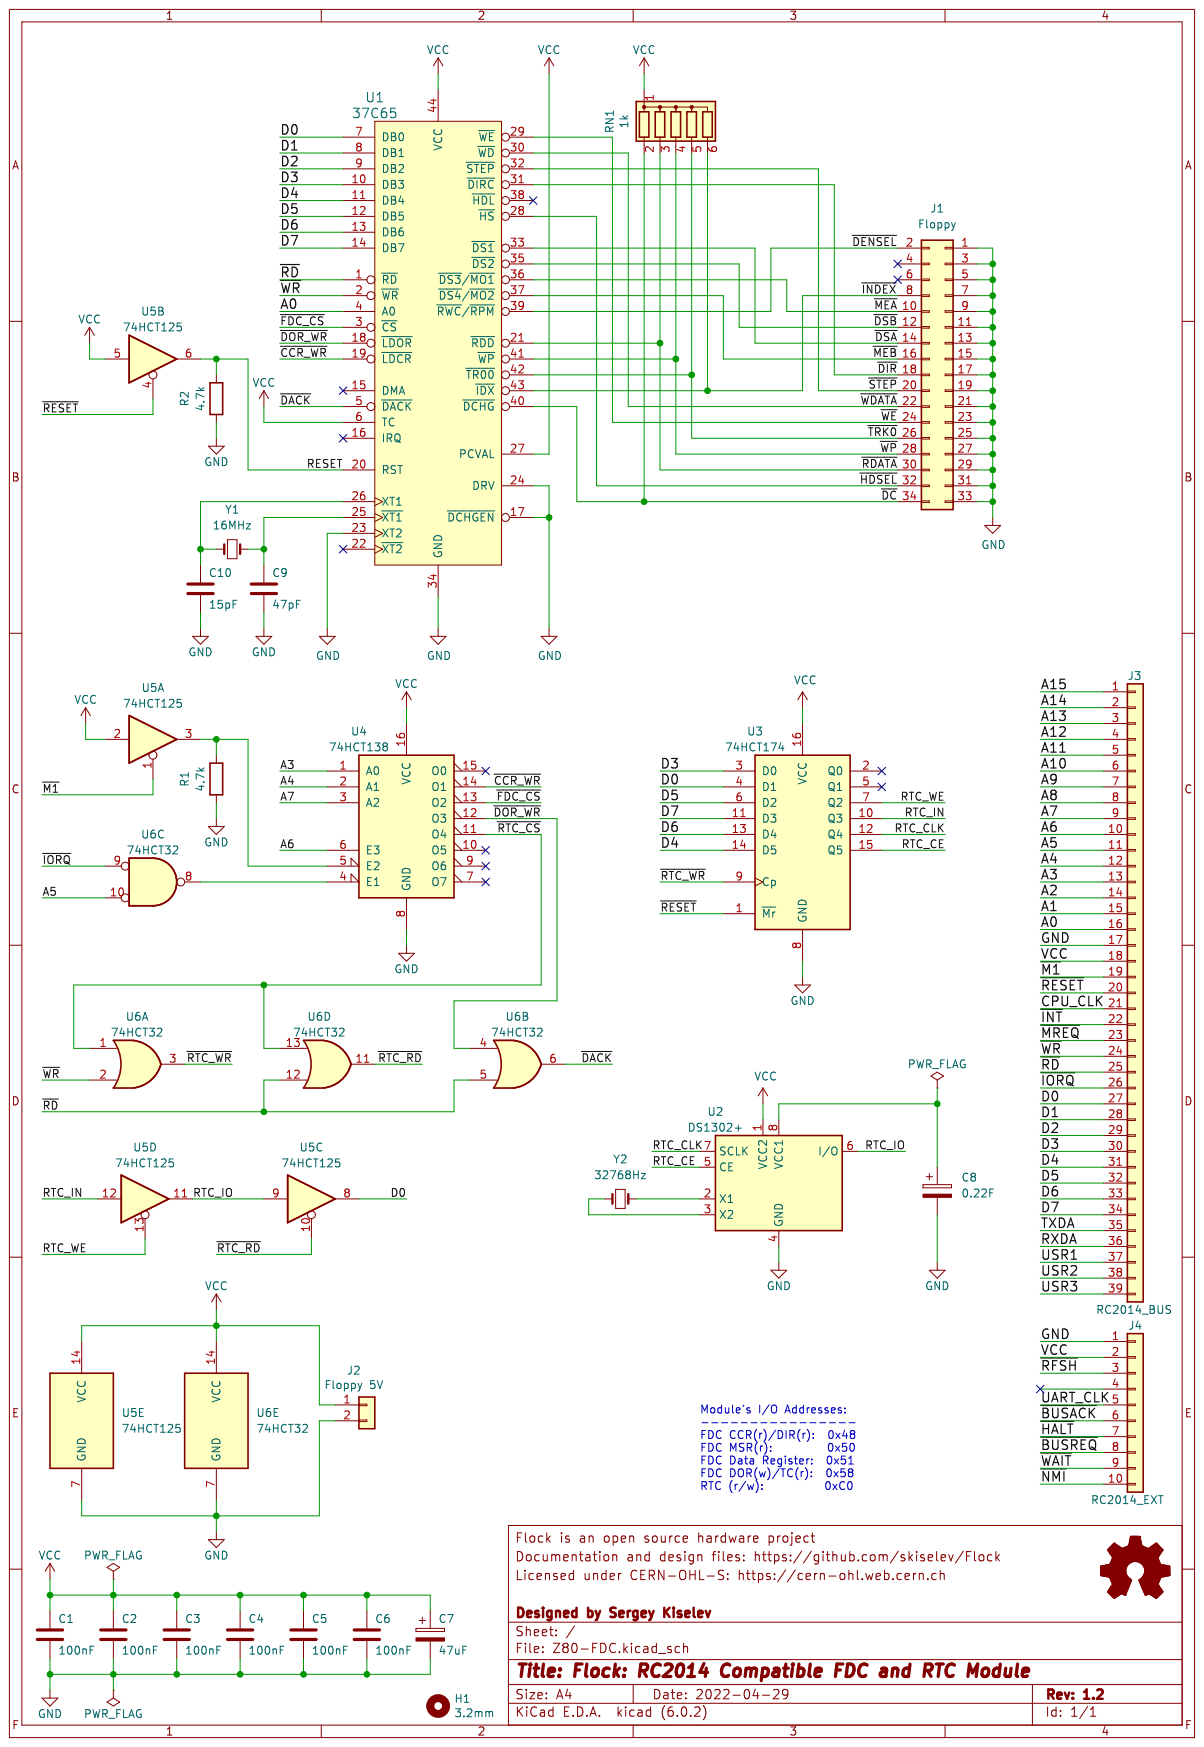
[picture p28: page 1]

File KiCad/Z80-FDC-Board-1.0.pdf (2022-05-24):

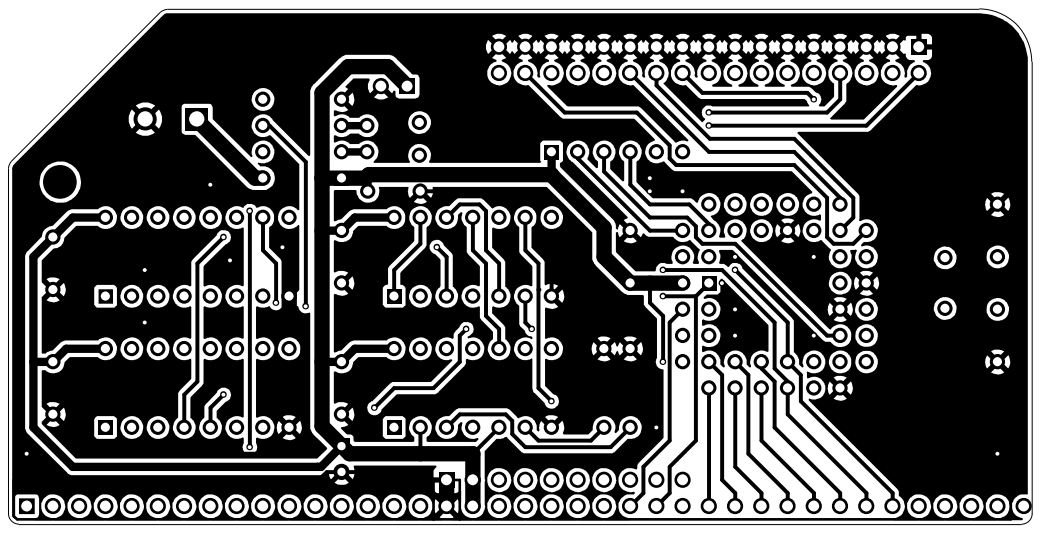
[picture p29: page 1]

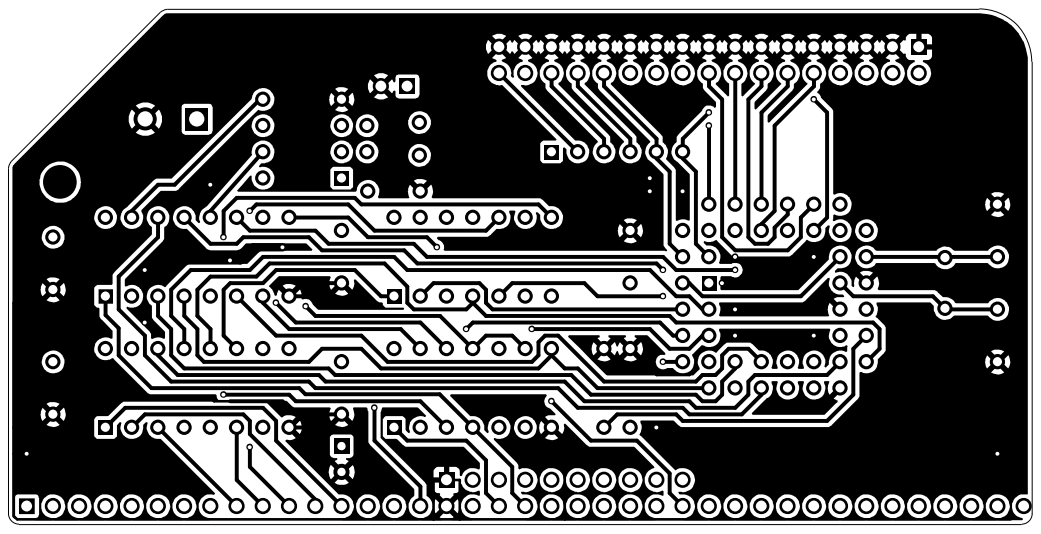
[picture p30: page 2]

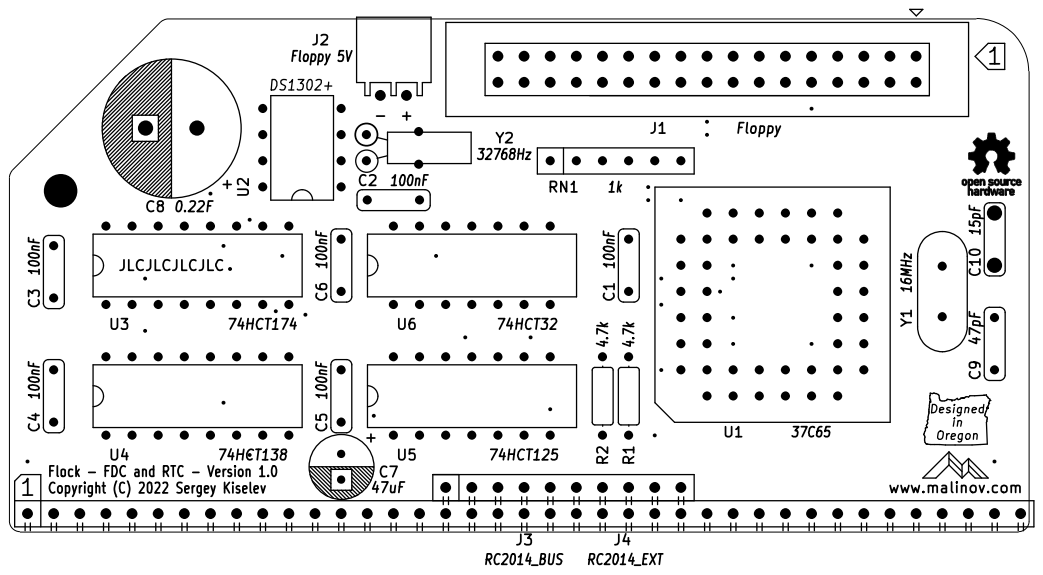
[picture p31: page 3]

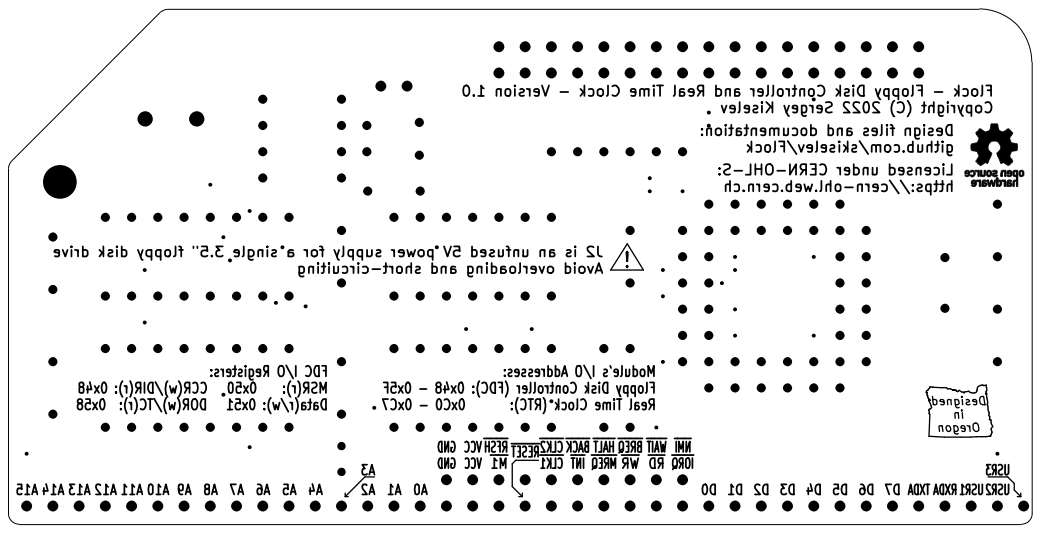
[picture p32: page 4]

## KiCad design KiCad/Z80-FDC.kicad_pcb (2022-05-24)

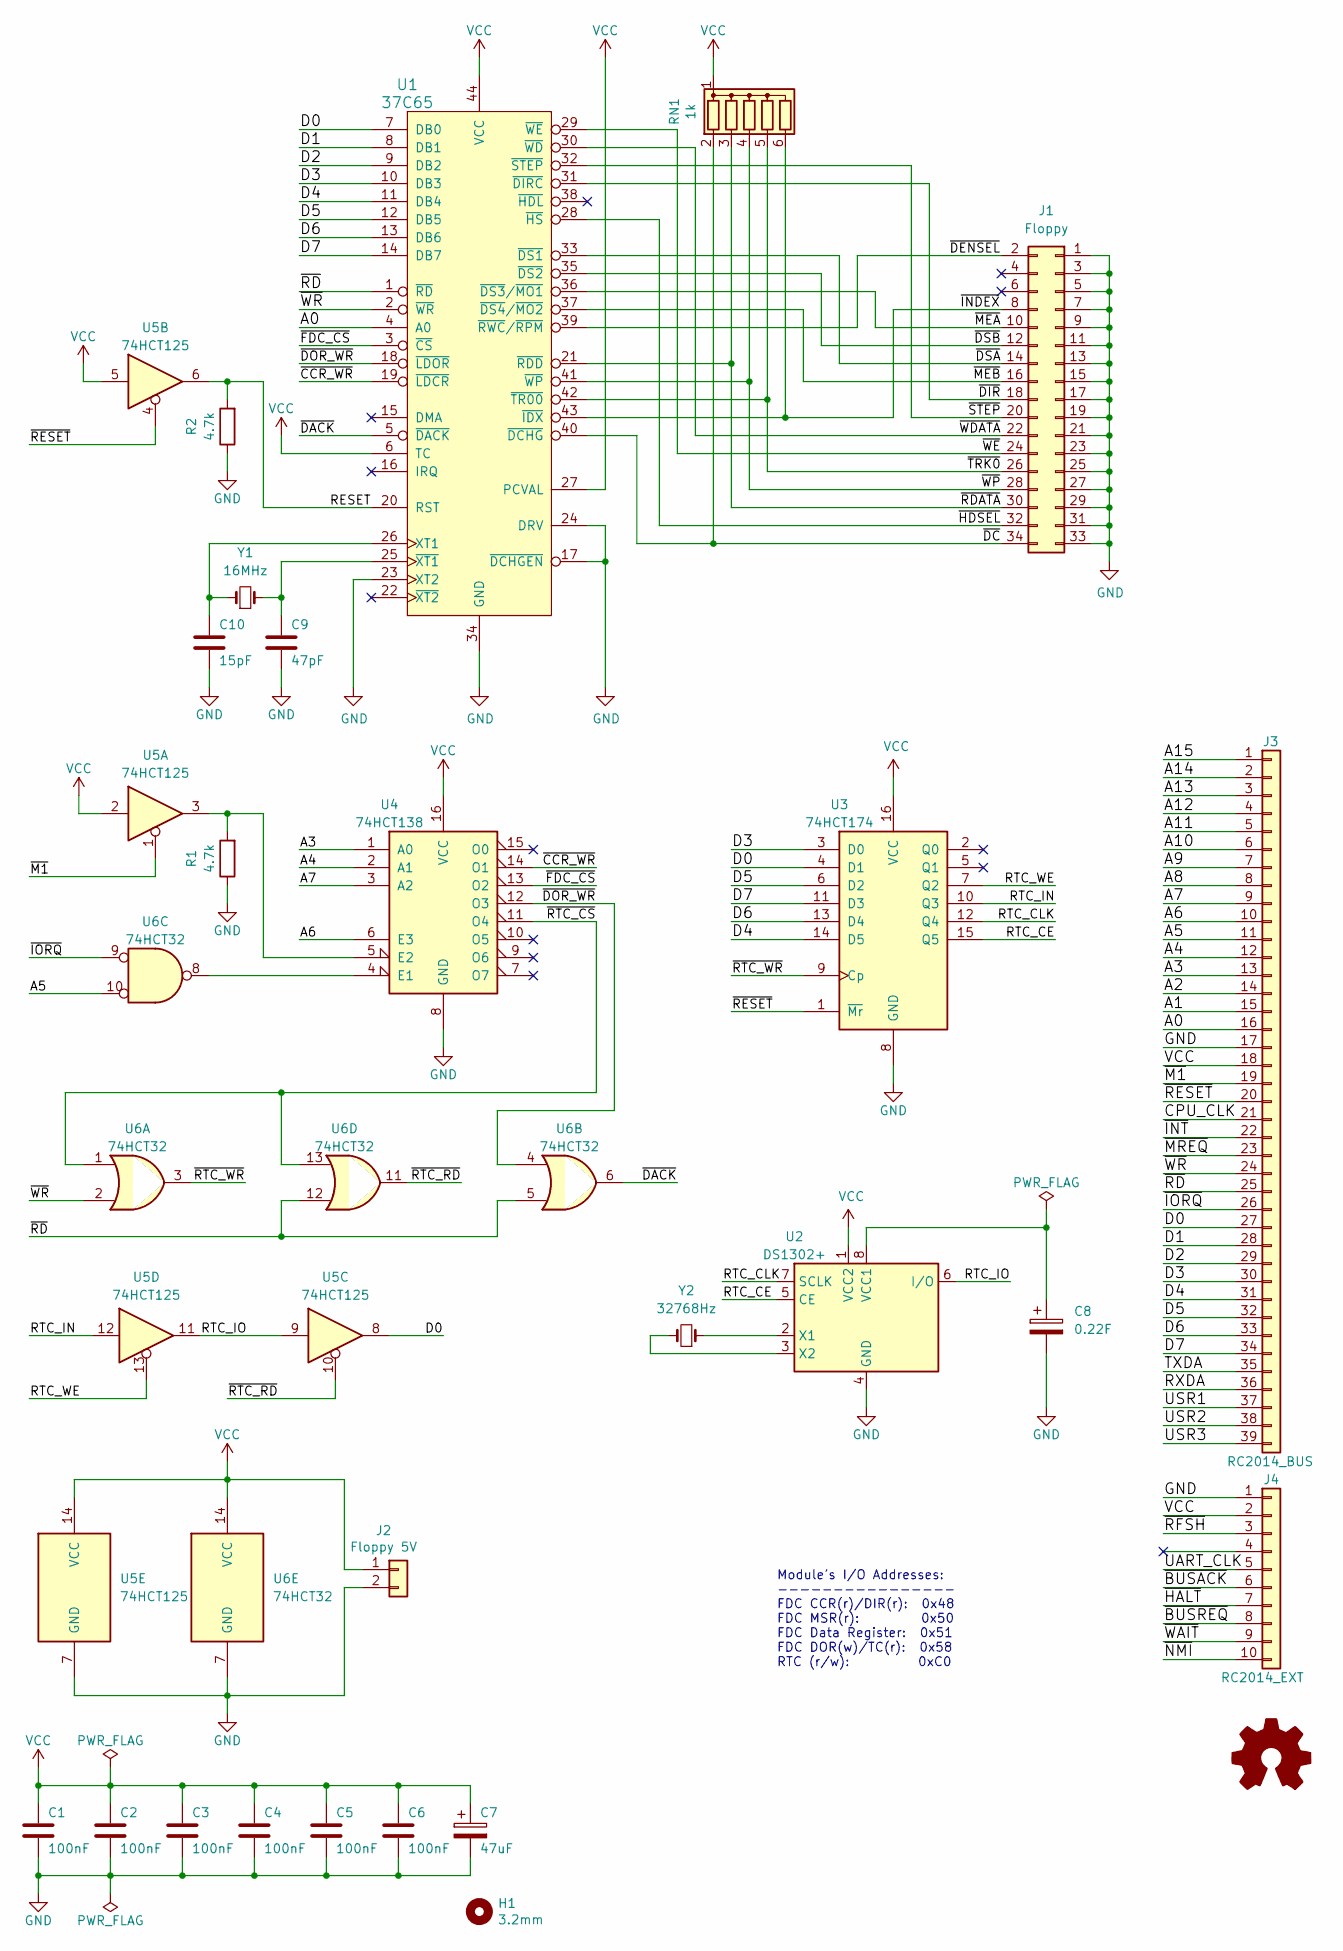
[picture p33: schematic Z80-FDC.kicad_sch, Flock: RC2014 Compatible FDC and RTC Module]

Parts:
C1, C2, C3, C4, C5, C6: 100nF; Cap_Cer_508
C7: 47uF; Cap_Elec_Radial_6.3mm
C8: 0.22F; Cap_Super_Radial_13.5mm
C9: 47pF; Cap_Cer_508
C10: 15pF; Cap_Cer_508
H1: 3.2mm; MountingHole_3.2mm_M3_DIN965
J1: Floppy; Conn_Pin_Header_17x2_2.54mm_Shrouded
J2: Floppy 5V; Conn_TE_2-644488-2_2P_2.54mm
J3: RC2014_BUS; Conn_Pin_Header_39x1_2.54mm_Right_Angle
J4: RC2014_EXT; Conn_Pin_Header_10x1_2.54mm_Right_Angle
LOGO1: Logo_Open_Hardware_Small; OSHW-Logo_5.7x6mm_SilkScreen
R1, R2: 4.7k; Res_762
RN1: 1k; Conn_SIL6
U1: 37C65; IC_PLCC44_TH
U2: DS1302+; IC_DIP8_300
U3: 74HCT174; IC_DIP16_300
U4: 74HCT138; IC_DIP16_300
U5: 74HCT125; IC_DIP14_300
U6: 74HCT32; IC_DIP14_300
Y1: 16MHz; Crystal_HC-49U_Vert
Y2: 32768Hz; Crystal_32K_Horiz

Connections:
/A0: J3.16, U1.4 (A0)
/A1: J3.15
/A2: J3.14
/A3: J3.13, U4.1 (A0)
/A4: J3.12, U4.2 (A1)
/A5: J3.11, U6.10
/A6: J3.10, U4.6 (E3)
/A7: J3.9, U4.3 (A2)
/A8: J3.8
/A9: J3.7
/A10: J3.6
/A11: J3.5
/A12: J3.4
/A13: J3.3
/A14: J3.2
/A15: J3.1
/CPU_CLK: J3.21
/D0: J3.27, U1.7 (DB0), U3.4 (D1), U5.8
/D1: J3.28, U1.8 (DB1)
/D2: J3.29, U1.9 (DB2)
/D3: J3.30, U1.10 (DB3), U3.3 (D0)
/D4: J3.31, U1.11 (DB4), U3.14 (D5)
/D5: J3.32, U1.12 (DB5), U3.6 (D2)
/D6: J3.33, U1.13 (DB6), U3.13 (D4)
/D7: J3.34, U1.14 (DB7), U3.11 (D3)
/RESET: R2.2, U1.20 (RST), U5.6
/RTC_CE: U2.5 (CE), U3.15 (Q5)
/RTC_CLK: U2.7 (SCLK), U3.12 (Q4)
/RTC_IN: U3.10 (Q3), U5.12
/RTC_IO: U2.6 (I/O), U5.9, U5.11
/RTC_WE: U3.7 (Q2), U5.13
/RXDA: J3.36
/TXDA: J3.35
/UART_CLK: J4.5
/USR1: J3.37
/USR2: J3.38
/USR3: J3.39
/~BUSACK: J4.6
/~BUSREQ: J4.8
/~CCR_WR: U1.19 (~LDCR), U4.14 (O1)
/~DACK: U1.5 (~DACK), U6.6
/~DC: J1.34, RN1.2 (R1), U1.40 (~DCHG)
/~DENSEL: J1.2, U1.39 (~RWC/~RPM)
/~DIR: J1.18, U1.31 (~DIRC)
/~DOR_WR: U1.18 (~LDOR), U4.12 (O3), U6.4
/~DSA: J1.14, U1.33 (~DS1)
/~DSB: J1.12, U1.35 (~DS2)
/~FDC_CS: U1.3 (~CS), U4.13 (O2)
/~HALT: J4.7
/~HDSEL: J1.32, U1.28 (~HS)
/~INDEX: J1.8, RN1.6 (R5), U1.43 (~IDX)
/~INT: J3.22
/~IORQ: J3.26, U6.9
/~M1: J3.19, U5.1
/~MEA: J1.10, U1.36 (~DS3/~MO1)
/~MEB: J1.16, U1.37 (~DS4/~MO2)
/~MREQ: J3.23
/~NMI: J4.10
/~RDATA: J1.30, RN1.3 (R2), U1.21 (~RDD)
/~RD: J3.25, U1.1 (~RD), U6.5, U6.12
/~RESET: J3.20, U3.1 (~Mr), U5.4
/~RFSH: J4.3
/~RTC_CS: U4.11 (O4), U6.1, U6.13
/~RTC_RD: U5.10, U6.11
/~RTC_WR: U3.9 (Cp), U6.3
/~STEP: J1.20, U1.32 (~STEP)
/~TRK0: J1.26, RN1.5 (R4), U1.42 (~TR00)
/~WAIT: J4.9
/~WDATA: J1.22, U1.30 (~WD)
/~WE: J1.24, U1.29 (~WE)
/~WP: J1.28, RN1.4 (R3), U1.41 (~WP)
/~WR: J3.24, U1.2 (~WR), U6.2
GND: C1.2, C2.2, C3.1, C4.2, C5.2, C6.2, C7.2, C8.2, C9.2, C10.2, J1.1, J1.3, J1.5, J1.7, J1.9, J1.11, J1.13, J1.15, J1.17, J1.19, J1.21, J1.23, J1.25, J1.27, J1.29, J1.31, J1.33, J2.2, J3.17, J4.1, R1.1, R2.1, U1.17 (~DCHGEN), U1.23 (XT2), U1.24 (DRV), U1.34 (GND), U2.4 (GND), U3.8 (GND), U4.8 (GND), U5.7 (GND), U6.7 (GND)
unnamed: C8.1, U2.8 (VCC1)
unnamed: C9.1, U1.25 (~XT1), Y1.2
unnamed: C10.1, U1.26 (XT1), Y1.1
unnamed: R1.2, U4.5 (E2), U5.3
unnamed: U2.2 (X1), Y2.1
unnamed: U2.3 (X2), Y2.2
unnamed: U4.4 (E1), U6.8
VCC: C1.1, C2.1, C3.2, C4.1, C5.1, C6.1, C7.1, J2.1, J3.18, J4.2, RN1.1 (common), U1.6 (TC), U1.27 (PCVAL), U1.44 (VCC), U2.1 (VCC2), U3.16 (VCC), U4.16 (VCC), U5.2, U5.5, U5.14 (VCC), U6.14 (VCC)

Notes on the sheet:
Module's I/O Addresses: ---------------- FDC CCR(r)/DIR(r): 0x48 FDC MSR(r): 0x50 FDC Data Register: 0x51 FDC DOR(w)/TC(r): 0x58 RTC (r/w): 0xC0

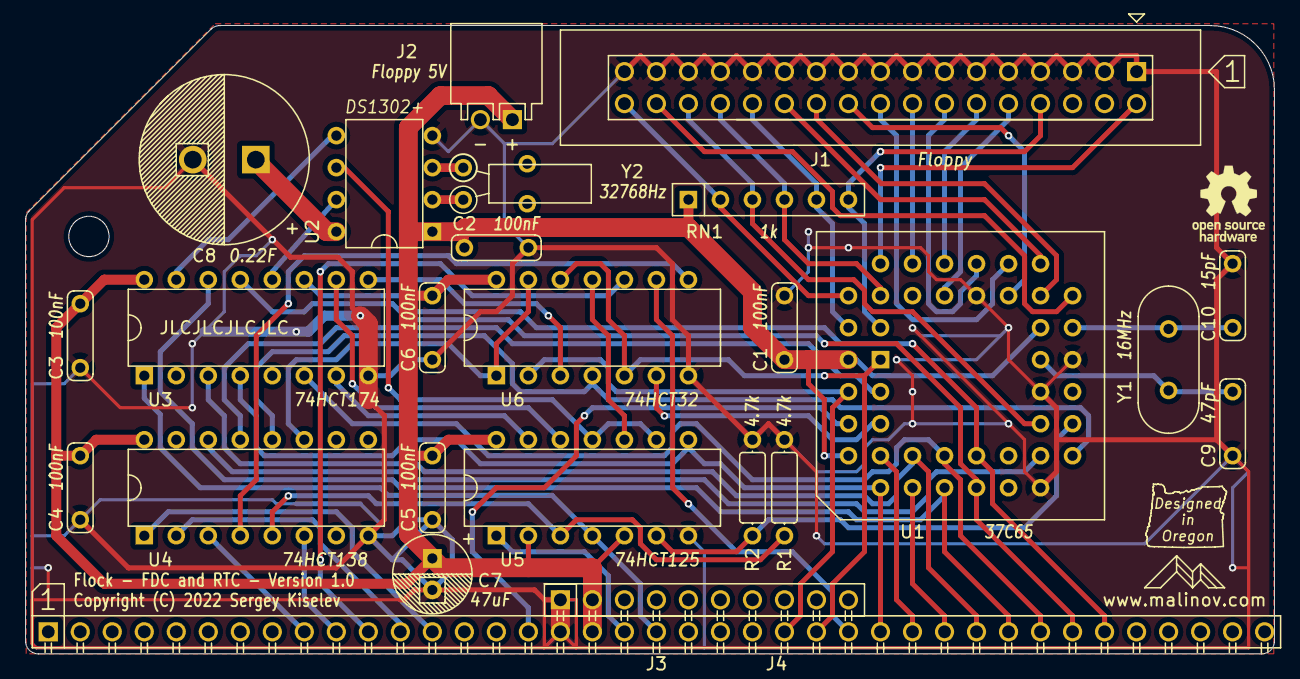
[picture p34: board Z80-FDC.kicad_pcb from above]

Board: 2 copper layers, 99.1 x 49.9 mm, 28 parts (1 on the bottom side), 56 nets.

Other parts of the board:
LOGO1#2: Logo_Open_Hardware_Small; OSHW-Logo_5.7x6mm_SilkScreen

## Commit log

2023-02-18 Update Assembly_Instructions.md
    Added information that you can safely extract pin 3 from J1 to accommodate keyed cables.
2023-02-18 Update Assembly_Instructions.md
    Added information for FAT floppy formatting.

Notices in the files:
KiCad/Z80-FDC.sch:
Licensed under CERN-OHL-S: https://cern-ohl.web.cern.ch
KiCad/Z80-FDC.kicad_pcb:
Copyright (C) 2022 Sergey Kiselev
